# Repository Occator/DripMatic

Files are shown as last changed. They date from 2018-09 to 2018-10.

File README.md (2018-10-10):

# DripMatic - Automated Irrigation System

## Goal of the project
DripMatic is a solar powered mikrocontroller-based automated irrigation system for the small and middle sized outdoor vegetables production. Its WSAN (wireless sensor-actor-network) collects through smart-sensors crop specific data i.e.: soil-moisture, humidity, temperature, rainfall, wind direction and wind speed etc. The collected data will be compared with pre-defined parameter in a database. After calculating the amount of water which needs to be applied, the system analysis the weather data and decide the irrigation time and duration. Crop specific data will be stored on an SD-Card and afterwards transmitted to a server if available.

## hardware requirements

- Arduino UNO Rev.3
- DS1302 RTC-Module
- SPI MicroSD-Card Reader
- LCD-Module 4x20 with ST7066U-0A Controller
- I2C PCF8574 module
- MPX 5100DP Pressure Transducer
- 3 x LEDs (red, yellow, green)
- ESP8266 Wifi Development Board

## docs
this folder will contain all developed and designed hardware components like:
- stl-files for printing parts (i.e. mounting for pressure transducer, moulds for seal rings etc.)
- PCBs for sensor- and actor nodes
- knowledge base (i.e. cultivating techniques, test data record etc.)

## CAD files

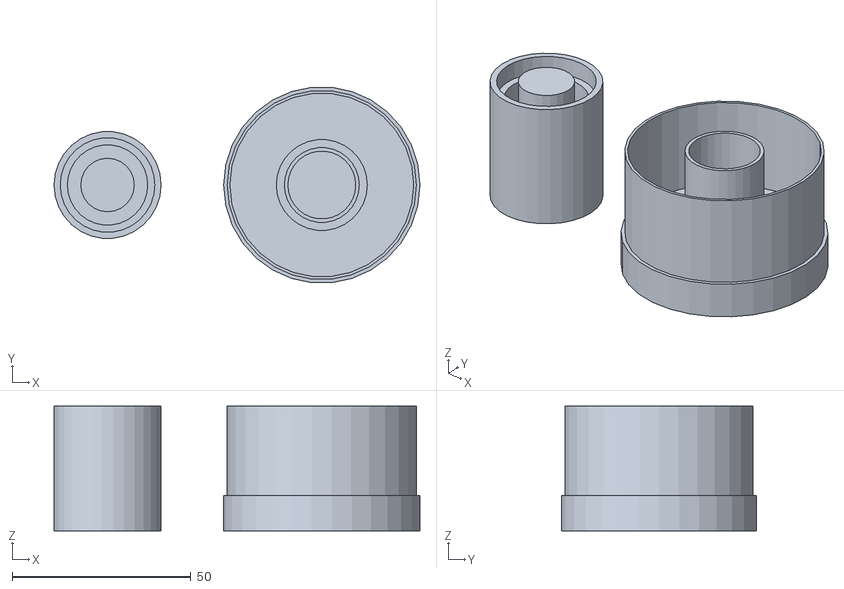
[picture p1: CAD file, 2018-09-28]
doc/3d-printparts/kerzendichtung_01.stl
102.5 x 54.7 x 35.0

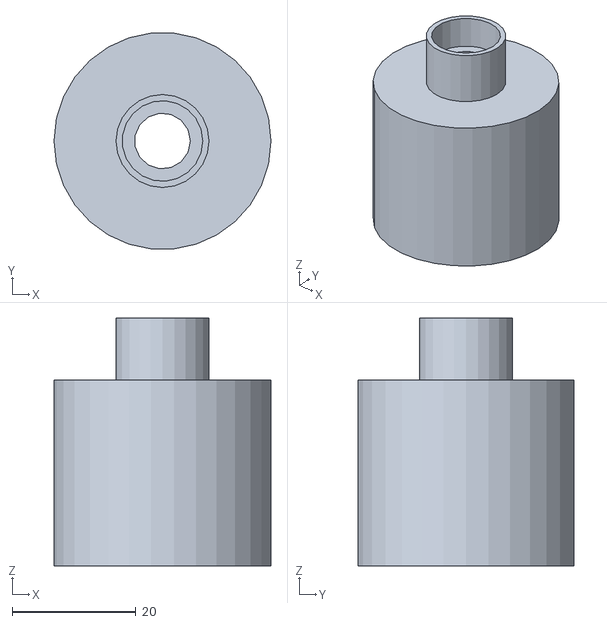
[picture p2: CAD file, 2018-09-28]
doc/3d-printparts/stopper_guss_oben.stl
35.0 x 34.8 x 40.0

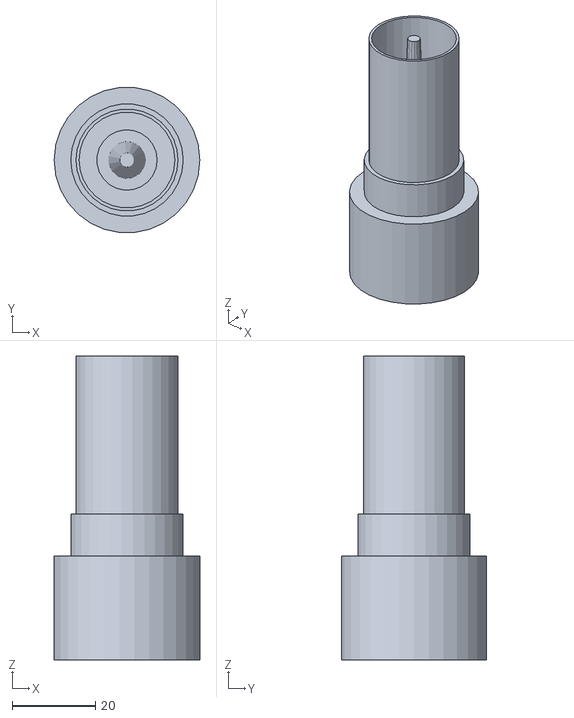
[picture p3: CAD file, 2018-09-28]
doc/3d-printparts/stopper_guss_unten.stl
35.0 x 34.8 x 73.0

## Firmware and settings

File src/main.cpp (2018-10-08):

#include <avr/io.h>
#include <util/delay.h>
#include <stdint.h>
#include <stdlib.h>
#include <stdio.h>
#include "twi_module.h"
#include "lcd_module.h"
#include "adc_pin.h"
#include "rtc_3w.h"
#include "sdcard_module.h"
#include "uart_module.h"
#include "diskio.h"
#include "ff.h"


int main(){
	cUART::getInstance().init();
	cUART::getInstance().write_String("enter main\r\n");
	void DisplayDate(cLCD *lcd2004);
	void DisplayTime(cLCD *lcd2004);
	bool sensorReading = true;
	int16_t runningNumber { 0 };

	char convertBuffer[5];

	TCHAR header0[] = "no.";
	TCHAR header1[] = "DATE";
	TCHAR header2[] = "TIME";
	TCHAR header3[] = "Tensio-Val";

	cIOPin rtcCE(&PORTD, 2, cIOPin::output);
	cIOPin rtcIO(&PORTD, 3, cIOPin::output);
	cIOPin rtcSCLK(&PORTD, 4, cIOPin::output);
	cDeviceRTC::GetInstance().init(&rtcCE, &rtcIO, &rtcSCLK);


	FATFS fatFS;
	FIL records;
	FRESULT res_mount, res_open;

	cTWI ioExpander(0x4E);

	cIOPin redLED(&PORTD, 5, cIOPin::output);
	cIOPin yellowLED(&PORTD, 6, cIOPin::output);
	cIOPin greenLED(&PORTD, 7, cIOPin::output);

	cADCPin tensiometer(0);
	cLCD userDisplay(&ioExpander);

	res_mount = f_mount(&fatFS, "", 0);
	if(res_mount == FR_OK)
	{
		_delay_ms(10);
		res_open = f_open(&records, "records.csv", FA_WRITE | FA_OPEN_ALWAYS | FA_READ);
		if(res_open == FR_OK)
		{
			_delay_ms(10);
			f_puts(header0, &records);
			f_putc(',', &records);
			f_puts(header1, &records);
			f_putc(',', &records);
			f_puts(header2, &records);
			f_putc(',', &records);
			f_puts(header3, &records);
			f_putc('\n', &records);

		}
		f_close(&records);
	}

	userDisplay.SetCursor(5,1);
	userDisplay.WriteString("DripMatic");
	userDisplay.SetCursor(7, 2);
	userDisplay.WriteString("ver.0.1");
	_delay_ms(3000);
	userDisplay.Clear();

	uint16_t currentValue { 0 };
	uint16_t lastValue { 0 };

	cUART::getInstance().write_String("enter infinite loop");
	for(;;)
	{

		greenLED.SetPin(1);
		cDeviceRTC::GetInstance().update_rtcTime();

		DisplayDate(&userDisplay);
		DisplayTime(&userDisplay);

		userDisplay.WriteStringXY(0, 2, "last: ");
		userDisplay.WriteInt(lastValue);
		userDisplay.WriteStringXY(0, 3, "current: ");
		userDisplay.WriteInt(currentValue);

		if(!sensorReading){
			_delay_ms(30000);
			sensorReading = true;
		}

		if( ( (cDeviceRTC::GetInstance().rtcTime.minutes % 15 ) == 0) && (sensorReading) )
		{
			userDisplay.Clear();
			greenLED.SetPin(0);
			lastValue = currentValue;
			uint16_t adcValue = 0;
			uint8_t count  = 0;
			while(count < 50)
			{
				userDisplay.WriteStringXY(0, 0, "reading sensor...");
				yellowLED.TogglePin();
				adcValue += tensiometer.Read();
				count++;
				_delay_ms(10);
			}
			currentValue = adcValue / 50;

			userDisplay.WriteStringXY(0, 0, "Tensiometer-Value");
			userDisplay.WriteStringXY(0, 2, "last: ");
			userDisplay.WriteInt(lastValue);
			userDisplay.WriteStringXY(0, 3, "current: ");
			userDisplay.WriteInt(currentValue);
			_delay_ms(10000);

			res_open = open_append(&records, "records.csv");
			if(res_open == FR_OK)
			{
				itoa(runningNumber, convertBuffer, 10);
				f_puts(convertBuffer, &records);
				f_putc(',', &records);
				cDeviceRTC::GetInstance().update_rtcTime();
				itoa(cDeviceRTC::GetInstance().rtcTime.year, convertBuffer, 10);
				f_puts(convertBuffer, &records);
				f_putc('/', &records);
				itoa(cDeviceRTC::GetInstance().rtcTime.month, convertBuffer, 10);
				f_puts(convertBuffer, &records);
				f_putc('/', &records);
				itoa(cDeviceRTC::GetInstance().rtcTime.date, convertBuffer, 10);
				f_puts(convertBuffer, &records);
				f_putc(',', &records);
				itoa(cDeviceRTC::GetInstance().rtcTime.hours, convertBuffer, 10);
				f_puts(convertBuffer, &records);
				f_putc(':', &records);
				itoa(cDeviceRTC::GetInstance().rtcTime.minutes, convertBuffer, 10);
				f_puts(convertBuffer, &records);
				f_putc(':', &records);
				itoa(cDeviceRTC::GetInstance().rtcTime.seconds, convertBuffer, 10);
				f_puts(convertBuffer, &records);
				f_putc(',', &records);
				itoa(currentValue, convertBuffer, 10);
				f_puts(convertBuffer, &records);
				f_putc('\n', &records);
			}
			f_close(&records);

			userDisplay.Clear();
			greenLED.SetPin(1);
			sensorReading = false;
			runningNumber++;
		}
	}
}

void DisplayDate(cLCD *lcd)
{
	lcd->SetCursor(0, 0);
	// frame_date
	lcd->WriteInt(cDeviceRTC::GetInstance().rtcTime.year);
	lcd->WriteString("/");
	if(cDeviceRTC::GetInstance().rtcTime.month < 10)
	{
		 lcd->WriteString("0");
		 lcd->WriteInt(cDeviceRTC::GetInstance().rtcTime.month);
	}
	else
	{
		lcd->WriteInt(cDeviceRTC::GetInstance().rtcTime.month);
	}
	lcd->WriteString("/");
	if(cDeviceRTC::GetInstance().rtcTime.date < 10)
	{
		 lcd->WriteString("0");
		 lcd->WriteInt(cDeviceRTC::GetInstance().rtcTime.date);
	}
	else
	{
		lcd->WriteInt(cDeviceRTC::GetInstance().rtcTime.date);
	}
}

void DisplayTime(cLCD *lcd)
{
	lcd->SetCursor(15, 0);
	if(cDeviceRTC::GetInstance().rtcTime.hours < 10)
	{
		lcd->WriteString("0");
		lcd->WriteInt(cDeviceRTC::GetInstance().rtcTime.hours);
		lcd->WriteString(":");
	}
	else
	{
		lcd->WriteInt(cDeviceRTC::GetInstance().rtcTime.hours);
		lcd->WriteString(":");
	}
	if(cDeviceRTC::GetInstance().rtcTime.minutes < 10)
	{
		lcd->WriteString("0");
		lcd->WriteInt(cDeviceRTC::GetInstance().rtcTime.minutes);
	}
	else
	{
		lcd->WriteInt(cDeviceRTC::GetInstance().rtcTime.minutes);
	}
}

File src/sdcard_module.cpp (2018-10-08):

#include "sdcard_module.h"
#include "uart_module.h"
#include <util/delay.h>

cMicroSDModule::cMicroSDModule(cIOPin *chipSelect, cSPIModule * csDevice)
: _csPin(chipSelect), _spi(csDevice)
{
  cUART::getInstance().write_String("**init SD-Card in SPI-mode...\r\n");
  if (!_initSPIMode())
  {
    _isSuccessful = true;
  }
  else
  {
    _isSuccessful = false;
  }
}

cMicroSDModule::~cMicroSDModule()
{}


uint8_t cMicroSDModule::readSingleBlock(uint8_t *buffer, uint32_t startBlock)
{
  cUART::getInstance().write_String("**enter readSingleBlock\r\n");
    uint8_t response;
    response  = sendCommand(READ_SINGLE_BLOCK, ( (uint32_t)startBlock) << 9);
    if(response != 0x00)
    {
      return response;
    }

    _csAsserted();

    for(uint8_t retry = 0; retry < 50; retry++)
    {
      response = _spi->receive();
      if(response == SD_START_TOKEN)
      {
        retry = 0;
        break;
      }
    }

    for(uint16_t i = 0; i < BLOCK_LENGTH; i++)
    {
      *buffer++ = _spi->receive();
    }

    _spi->receive(); // discard incomming CRC - 16-bits
    _spi->receive();

    _spi->receive();
    _csDeasserted();

  cUART::getInstance().write_String("**exit readSingleBlock\r\n");
  return 0;
}

uint8_t cMicroSDModule::writeSingeBlock(uint8_t *buffer, uint32_t startBlock)
{
  cUART::getInstance().write_String("**enter writeSingleBlock\r\n");
    uint8_t response;
    response = sendCommand(WRITE_SINGLE_BLOCK, ( (uint32_t)startBlock) << 9);

    if(response != 0x00)
    {
      return response;
    }

    _csAsserted();

    _spi->transmit(0xFE);

    for(uint16_t i = 0; i < 512; i++)
    {
      _spi->transmit(*buffer++);
    }
    _spi->transmit(0xFF);
    _spi->transmit(0xFF);

    response = _spi->transmit(0xFF);

    if( (response & 0x1F) != 0x05)
    {
      _csDeasserted();
      return response;
    }

    while( !_spi->receive() );

    _csDeasserted();
    _spi->transmit(0xFF);
    _csAsserted();

    while( !_spi->receive() );

    _csDeasserted();
  cUART::getInstance().write_String("**exit writeSingleBlock\r\n");
  return 0;
}

uint8_t cMicroSDModule::_initSPIMode()
{
  uint8_t response, sdVersion;
  uint8_t retry {0};

  for(uint8_t i = 0; i < 10; i++)
  {
    _spi->transmit(0xFF);
  }

  _csAsserted();
  do
  {
    response = sendCommand(GO_IDLE_STATE, 0);
    retry++;
    if(retry > 15)
    {
      cUART::getInstance().write_String("**timeout... no card detected\r\n");
      return 1;
    }
  } while(response != 0x01);

  _csDeasserted();
  _spi->transmit(0xFF);
  _spi->transmit(0xFF);

  retry = 0;

  sdVersion = 2;

  do
  {
    response = sendCommand(SEND_IF_COND, 0x000001AA);
    retry++;
    if(retry > 15)
    {
      sdVersion = 1;
      _cardType = 1;
      break;
    }
  } while(response != 0x01);


  retry = 0;

  for(uint8_t j = 0; j < 10; j++)
  {
    response = _sendAppCmd();
    if(response == 0x00)
    {
      break;
    }
  }

  _sdhcFlag = 0;

  if(sdVersion == 2)
  {
    do
    {
      response = sendCommand(READ_OCR, 0);
      retry++;
      if(retry > 20)
      {
        _cardType = 0;
        break;
      }
    }while(response != 0x00);

    if(_sdhcFlag == 1)
    {
      _cardType = 2;
    }
    else
    {
      _cardType = 3;
    }
  }

  sendCommand(CRC_ON_OFF, 0);
  sendCommand(SET_BLOCK_LEN, BLOCK_LENGTH);

  return 0;
}

uint8_t cMicroSDModule::sendCommand(uint8_t command, uint32_t argument)
{
  uint8_t response, status;
  uint8_t retry {0};

  _csAsserted();

  _spi->transmit(command | 0x40);
  _spi->transmit(argument >> 24);
  _spi->transmit(argument >> 16);
  _spi->transmit(argument >> 8);
  _spi->transmit(argument);

  // it is recommended to send correct CRC for CMD8 (0x87) and CMD0 (0x95)
  if(command == SEND_IF_COND)
  {
    _spi->transmit(0x87);
  }
  else if(command == GO_IDLE_STATE)
  {
    _spi->transmit(0x95);
  }
  else
  {
    _spi->transmit(0xFF);
  }

  while( (response = _spi->receive()) == 0xFF)
  {
    if(retry++ > 20)
    {
      break;
    }
  }

  if(response == 0x00 && command == READ_OCR)
  {
    status = _spi->receive() & 0x40;  // first byte of OCR register (bits 31:24)
    if(status == 0x40)
    {
      _sdhcFlag = 1;
    }
    else
    {
      _sdhcFlag = 0;
    }
    _spi->receive();  // three remaining bytes of OCR register are discarded
    _spi->receive();
    _spi->receive();
  }

  _spi->receive();
  _csDeasserted();
  return response;
}

void cMicroSDModule::_csAsserted()
{
  _csPin->SetPin(0);
}

void cMicroSDModule::_csDeasserted()
{
  _csPin->SetPin(1);
}

uint8_t cMicroSDModule::_sendAppCmd()
{
  uint8_t response;

  for(uint8_t i = 0; i < 50; i++)
  {
    response = sendCommand(APP_CMD, 0);
    response = sendCommand(SD_SEND_OP_COND, 0x40000000);
    if(response == 0x00)
    {
      break;
    }
  }
  return response;
}

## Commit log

2017-11-21 added a text-file to keep track of progress
2017-11-21 text-file to keep track of progress
2017-11-21 added ADC-Class
2017-11-21 added ADC class
2017-11-21 fixed ADC class
2017-11-21 implemented ADC class and example for use
2017-11-21 fixed ADC class implementation
2017-11-21 added ADC folder to branch exp/ADC
2017-11-21 fixed ADC class directory
2017-11-28 fixed write_Int_XY() in class_lcd_1602.cpp
    [main.cpp]
2017-11-28 added pin class
2017-11-28 added i/o-pin class
2017-11-28 test circuit with additional implement temp sensor. problem: adc isn't changing pin to read diffent values of ldr and lm35
    [main.cpp]
2017-11-28 add motor.c
2017-11-28 änderungen in motor
2017-12-05 deleted motor.c
2017-12-05 fixed makefile renamed folder scr/ to src/
    [main.cpp]
2017-12-05 fixed includes in src/main.cpp and makefile
    [main.cpp]
2017-12-05 added to do-list to keep track
2017-12-05 solved adc multichannel problem
    [main.cpp]
2017-12-12 added RTC minutes dependent start condition for measuring Sensor value
2017-12-12 implemented threshold for irrigation and indicator LEDs: yellow for sensor-readings and red for irrigation need
2017-12-12 fixed tempValue conversion to °C
    [main.cpp]
2018-01-05 changed adc-ref
2018-01-05 changed to 20 samples per measurement
2018-01-05 rearranged date and time position; temperature position aswell
2018-02-13 simple loop for display sensor Value
2018-02-19 added OP-Amp-circuit; added status LED
2018-02-26 added if-clause to read every 15 min. Sensor value
2018-03-05 corrected naming for bits in SPI Control Register(SPR0)
    [spi_module.cpp]
2018-03-05 added SS-pin in master_init(), renamed send and receive
2018-03-05 renamed spi send()
2018-03-05 added clock-polarity and clock-phase to spi master_init()
2018-03-06 added MISO as Input, set CS-pin high, added temporary buffer to send_byte()
2018-03-08 fixed setting data direction in master_init()
    [spi_module.cpp]
2018-03-11 added _csSPI-pin to SPIModule
2018-03-12 added uart_module.h and .cpp
2018-03-12 changed name from USART to UART
2018-03-12 added uart_module.h to sdcard_module.h
2018-03-12 re-named functions in uart_module
2018-03-12 added uart_module to main, display debug-msg on screen
2018-03-12 seperated de-/asserting CS_Pin into transmit(data)
2018-03-13 added chipSelect pin to sdcard_module
2018-03-13 re-named uart-object in sdcard_module
2018-04-09 reworked transmit and receive methods in spi_module
    [sdcard_module.cpp, spi_module.cpp]
2018-04-09 removed chipSelect object from ctor spi-module
2018-04-11 put SS-pin high in SPI init_Master()
2018-04-11 switch _csPin to SS (PB2)
2018-05-28 changed spi speed to 400kHz
2018-06-02 do not receive correct response from ACMD41
    [sdcard_module.cpp]
2018-06-02 implemented correct init-sequence, card is now ready to receive commands
    [sdcard_module.cpp]
2018-06-11 fixed int-overflowand removed ocr-read
    [main.cpp, sdcard_module.cpp, spi_module.cpp]
2018-06-11 removed debug-print
2018-07-09 changed testing program: added delay to give sd card to power up
2018-07-21 implemented singleton pattern i uart_module.h
2018-07-21 implemented uartSingleton
2018-07-21 modified for uartSingleton testing
2018-07-22 changed reference to pointer in uart SIngleton implentation
2018-08-21 integrated uart singleton in main
2018-08-21 integrated uart singleton in diskio.cpp and sdcard_module.cpp
2018-09-28 stl-files for 3d-printed mouldings
    [kerzendichtung_01.stl, stopper_guss_oben.stl, stopper_guss_unten.stl]
2018-10-08 changed uart call-function
